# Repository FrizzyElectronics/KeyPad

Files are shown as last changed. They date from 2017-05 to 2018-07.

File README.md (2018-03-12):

# KeyPad
The Keypad module carries 4 push buttons and uses 4 different values resistors to indicate which buttons are pressed. Four buttons using only one pin on your Arduino! With just an analogRead call you can know the button. The Keypad is great for greating game controllers in combination with 3D printing.
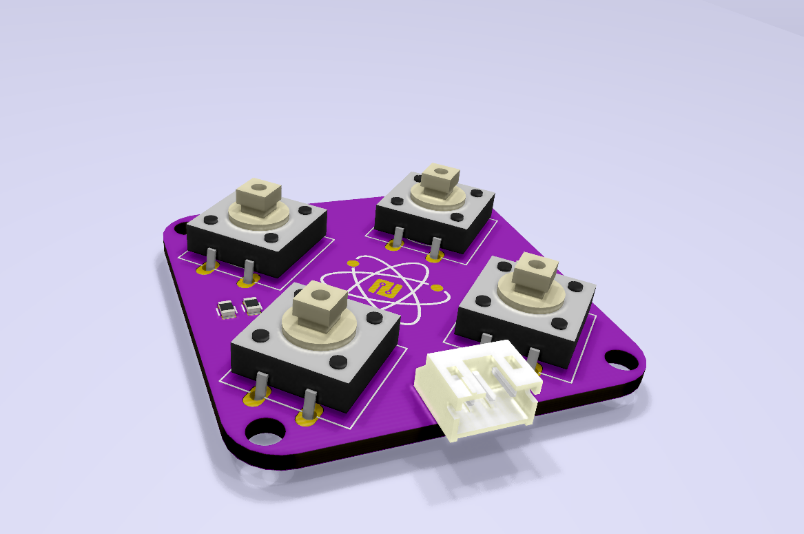
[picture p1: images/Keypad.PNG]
Keypad


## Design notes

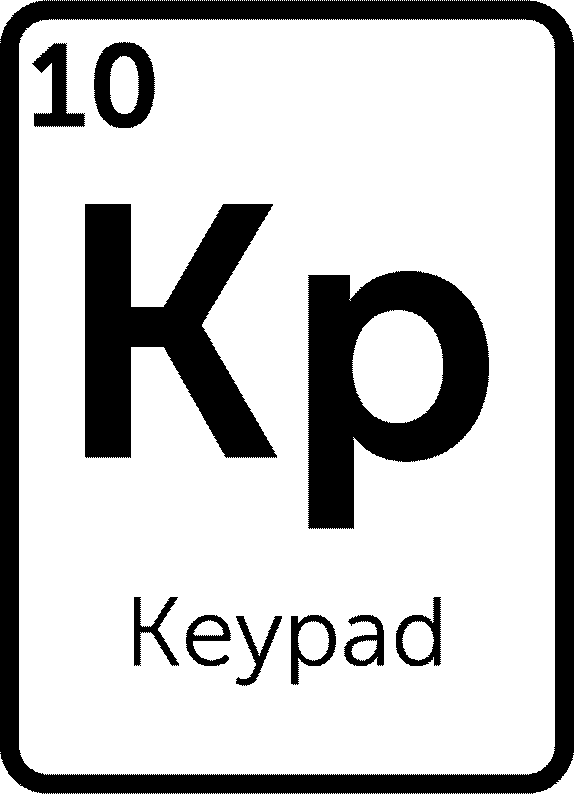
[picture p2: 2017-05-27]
images/Keypad_big.bmp

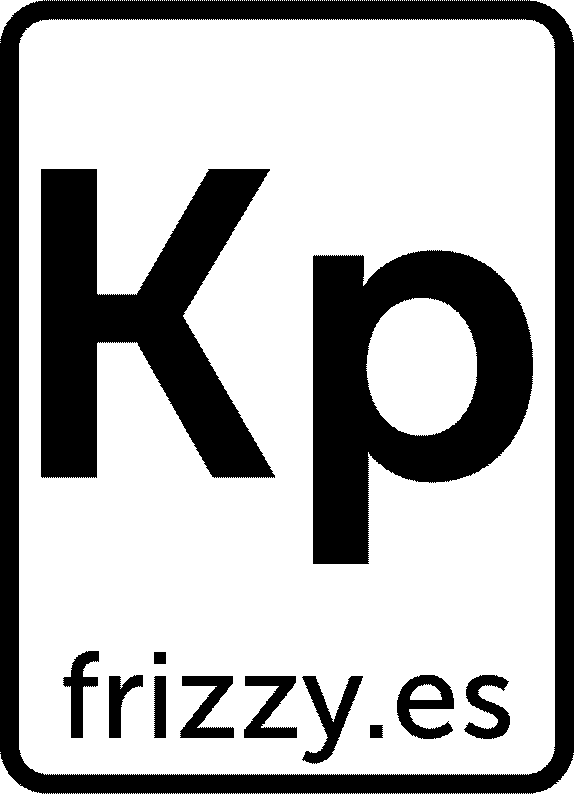
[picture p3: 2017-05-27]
images/Keypad_small.bmp

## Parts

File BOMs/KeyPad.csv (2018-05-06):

Id | Identificador | Empaquetado | Cantidad | Identificación | Suministrador y ref
1 | SW3,SW1,SW2,SW4 | SW_PUSH-12mm | 4 | SW_Push_Dual
2 | G*** | web | 1 | LOGO
3 | REF**,REF**,REF**,REF** | MountingHole_3.2mm_M3 | 4 | MountingHole_3.2mm_M3
4 | P1 | JST_PH_S3B-PH-K_03x2.00mm_Angled | 1 | CONN_01X03
5 | R1 | R_0805 | 1 | 2K
6 | R2 | R_0805 | 1 | 330R
7 | R3 | R_0805 | 1 | 620R
8 | R4 | R_0805 | 1 | 1K
9 | G*** | atom_XL | 1 | LOGO

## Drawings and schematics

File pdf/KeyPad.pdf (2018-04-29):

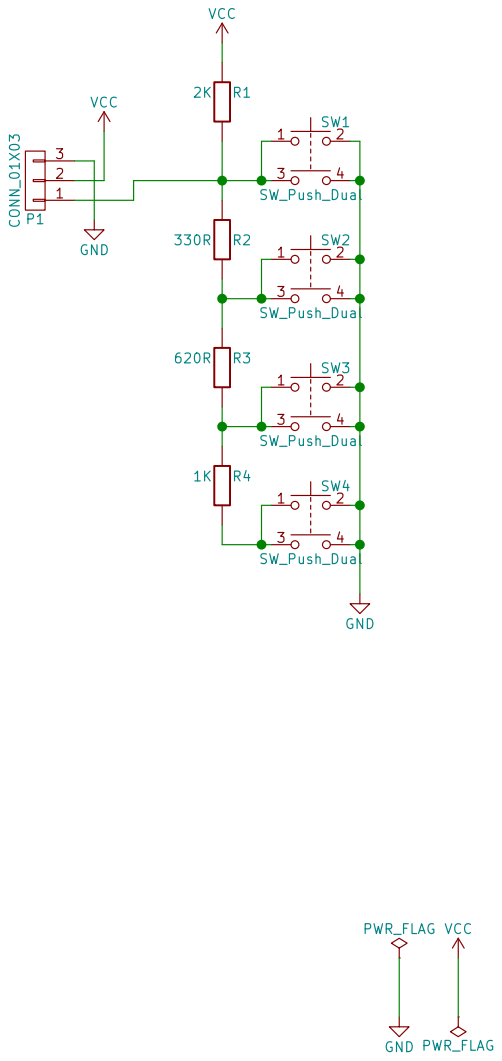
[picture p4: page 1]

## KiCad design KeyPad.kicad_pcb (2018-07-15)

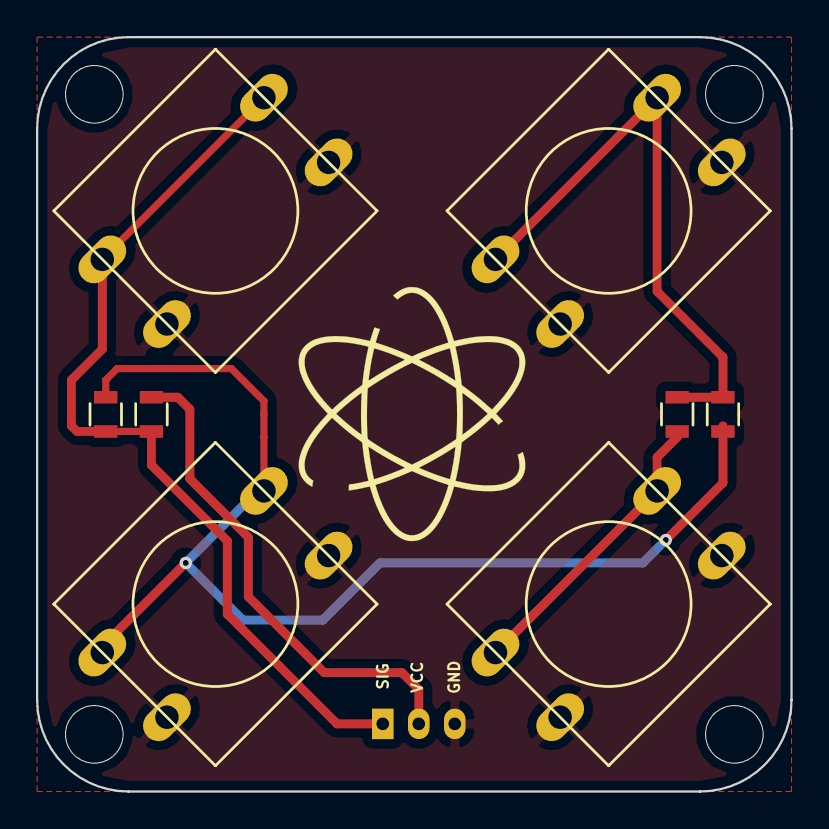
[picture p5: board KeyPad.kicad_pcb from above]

Board: 2 copper layers, 41.9 x 41.9 mm, 9 parts (0 on the bottom side), 6 nets.

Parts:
P1: CONN_01X03; JST_PH_S3B-PH-K_03x2.00mm_Angled
R1: 2K; R_0805
R2: 330R; R_0805
R3: 620R; R_0805
R4: 1K; R_0805
SW1, SW2, SW3, SW4: SW_Push_Dual; SW_PUSH-12mm

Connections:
GND: P1.3, SW1.2, SW2.2, SW3.2, SW4.2
unnamed: P1.1, R1.2, R2.1, SW1.1
unnamed: R2.2, R3.1, SW2.1
unnamed: R3.2, R4.1, SW3.1
unnamed: R4.2, SW4.1
VCC: P1.2, R1.1

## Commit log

2017-04-14 Esquematico terminado, DRC pasado y anotaciones echas
    [KeyPad.kicad_pcb, KeyPad.sch]
2017-04-16 Pcb enrrutada y esquinas redondeadas
    [KeyPad.kicad_pcb, KeyPad.sch]
2017-04-16 Error del conector reparado
    [KeyPad.kicad_pcb, KeyPad.sch]
2017-04-16 Version final, taladros añadidos, serigrafia lista
    [KeyPad.kicad_pcb]
2017-05-14 Taladros reparados, los anteriores eran muy pequeños
    [KeyPad.kicad_pcb]
2017-05-14 Mandado a fabrica
    [KeyPad.sch]
2017-05-27 Logos
    Small and big logos for the board
2018-01-08 archivos estandarizados para compartir
    [KeyPad.kicad_pcb, KeyPad.sch]
2018-01-10 3D añadido
    [KeyPad.kicad_pcb]
2018-02-10 conector cambiado
    [KeyPad.kicad_pcb, KeyPad.sch]
2018-02-12 Logo cambiado
    [KeyPad.kicad_pcb]
2018-02-24 Logos cambiados
    [KeyPad.kicad_pcb]
2018-03-03 Arbol de carpetas cambiado
    [KeyPad.kicad_pcb]
2018-03-12 Added board render
2018-03-12 Added board render image to readme
2018-03-12 Board render added
2018-05-06 BOM exportado
    [KeyPad.csv]
2018-07-15 Gerbers exportados
    [KeyPad-B.Cu.gbl, KeyPad-B.Mask.gbs, KeyPad-B.SilkS.gbo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]
